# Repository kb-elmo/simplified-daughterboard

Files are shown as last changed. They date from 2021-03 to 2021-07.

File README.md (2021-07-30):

# Simplified USB-C Daughterboard

[][cc-by-sa] [](https://opensource.com/resources/what-open-hardware)
<a href="https://ko-fi.com/kb_elmo">kofibadge</a>

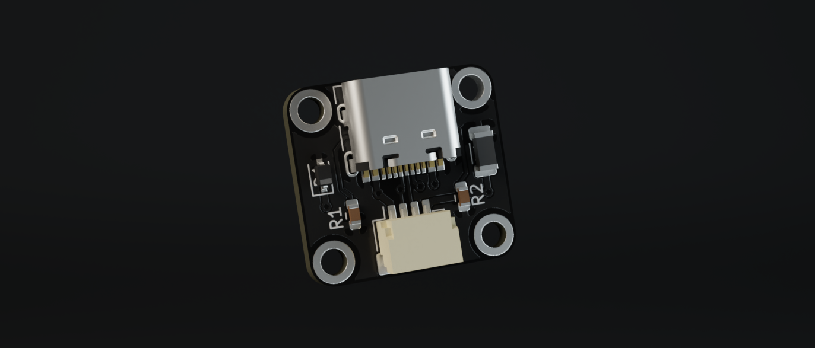
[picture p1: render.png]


This daughterboard features minimal electronics required for breaking out the VBUS, data and ground lines from a USB type C port.  
It includes a basic USB shielding circuit but has no ESD protection or fuse built in.

Fuse and (optional) ESD protection should be added on the main PCB if you want to use this for your project.

The daughterboard is pinout and size compatible with the [Unified Daughterboard by ai03](https://github.com/ai03-2725/Unified-Daughterboard).

Since the single PCB alone is too small for SMT assembly from JLCPCB and automatic panel assembly is currently not possible with them I created a 2x2 panelized version that works with JLCPCB assembly. You can find it in the fab files (linked below).

---

[Panelized PCB](fab/sDB_panel.kicad_pcb)

[Gerbers](fab/gerbers.zip)

[LCSC BOM](fab/bom.csv)

[JLC CPL](fab/pos.csv)

[USB connector](https://lcsc.com/product-detail/USB-Type-C_Korean-Hroparts-Elec-TYPE-C-31-M-12_C165948.html)

[JST connector](https://www.digikey.com/product-detail/en/jst-sales-america-inc/SM04B-SRSS-TB-LF-SN/455-1804-1-ND/926875)

---

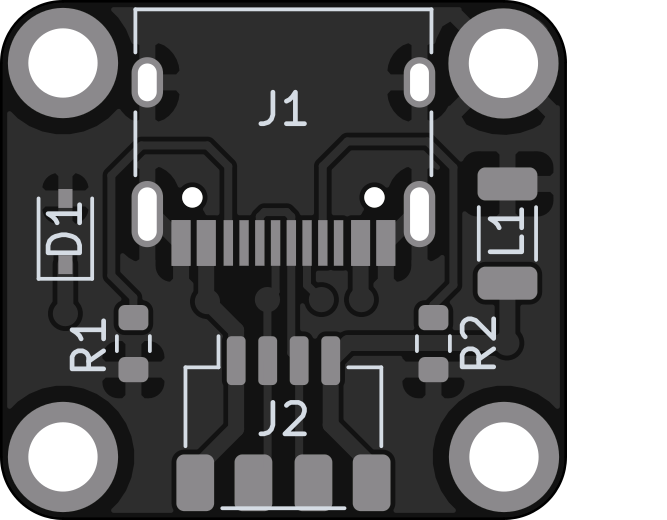
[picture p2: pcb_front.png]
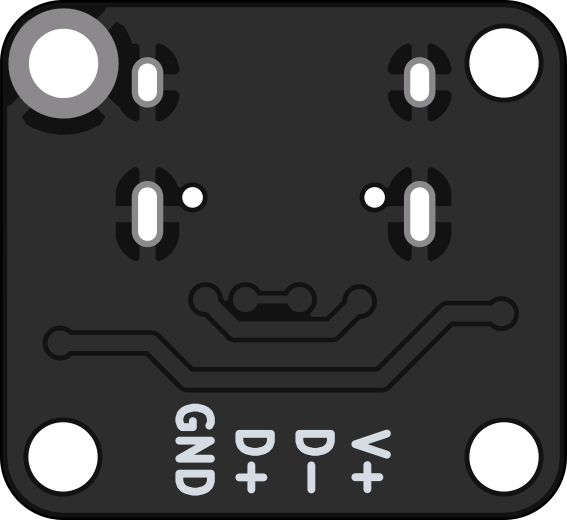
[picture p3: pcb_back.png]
 

This work is licensed under a
[Creative Commons Attribution-ShareAlike 4.0 International License][cc-by-sa].

[][cc-by-sa]

[cc-by-sa]: http://creativecommons.org/licenses/by-sa/4.0/
[cc-by-sa-image]: https://licensebuttons.net/l/by-sa/4.0/88x31.png
[cc-by-sa-shield]: https://img.shields.io/badge/License-CC%20BY--SA%204.0-lightgrey.svg
[os-love]: https://badges.frapsoft.com/os/v2/open-source.png?v=103

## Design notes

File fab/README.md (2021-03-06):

## Panelized PCB for JLCPCB SMT assembly
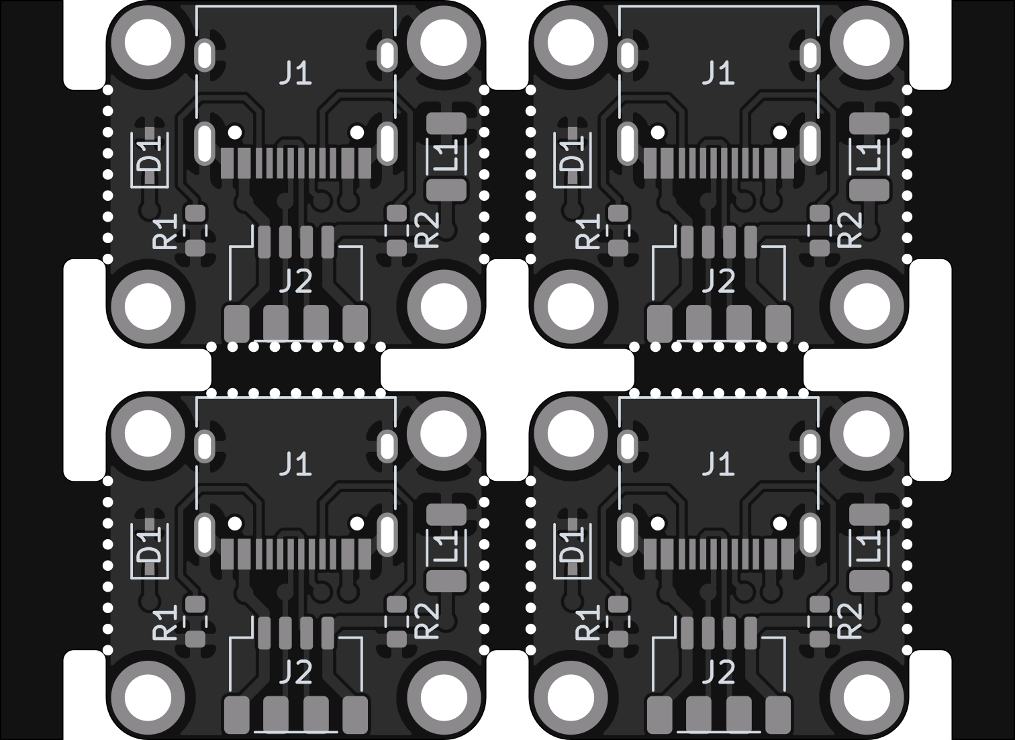
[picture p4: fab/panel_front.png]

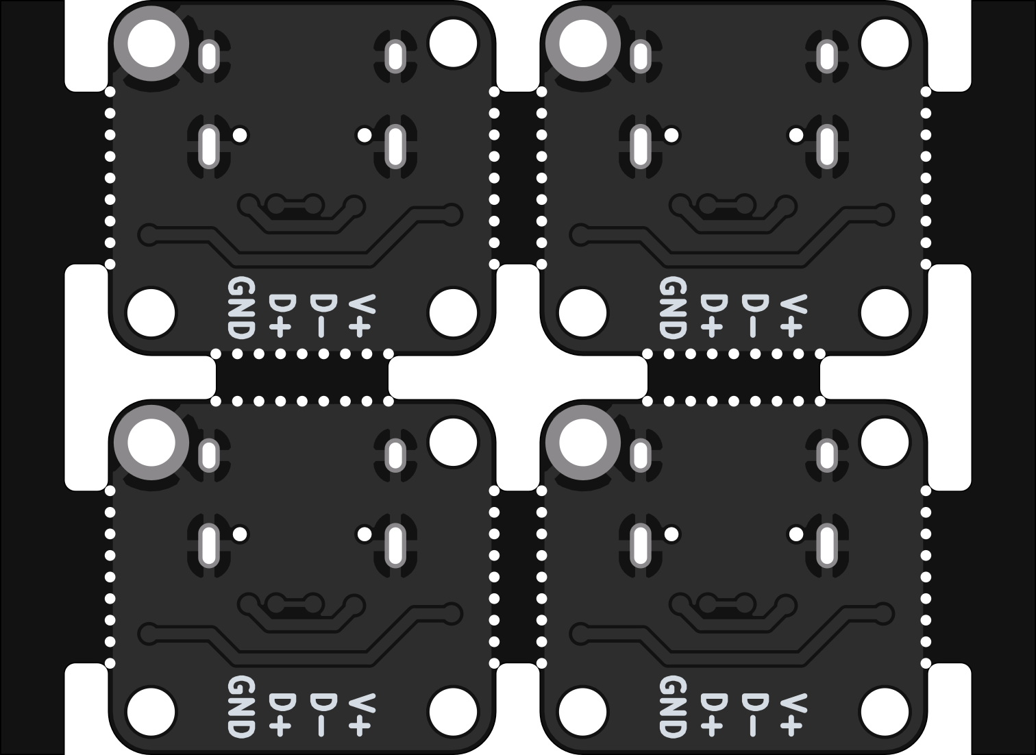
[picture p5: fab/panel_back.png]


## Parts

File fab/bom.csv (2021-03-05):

Comment | Designator | Footprint | LCSC
Conn_01x04 | J2 | custom_parts:JST_SH_SM04B-SRSS-TB_1x04-1MP_P1.00mm_Horizontal
USB_C_Receptacle_USB2.0 | J1 | Connector_USB:USB_C_Receptacle_HRO_TYPE-C-31-M-12 | C165948
5.6k | R1,R2 | Resistor_SMD:R_0603_1608Metric | C23189
L_Core_Ferrite | L1 | Inductor_SMD:L_1206_3216Metric | C33600
D_TVS | D1 | Diode_SMD:D_SOD-323 | C151996
MountingHole_Pad | H1 | custom_parts:Generic-Mounthole-dual
MountingHole | H2,H3,H4 | custom_parts:Generic-Mounthole

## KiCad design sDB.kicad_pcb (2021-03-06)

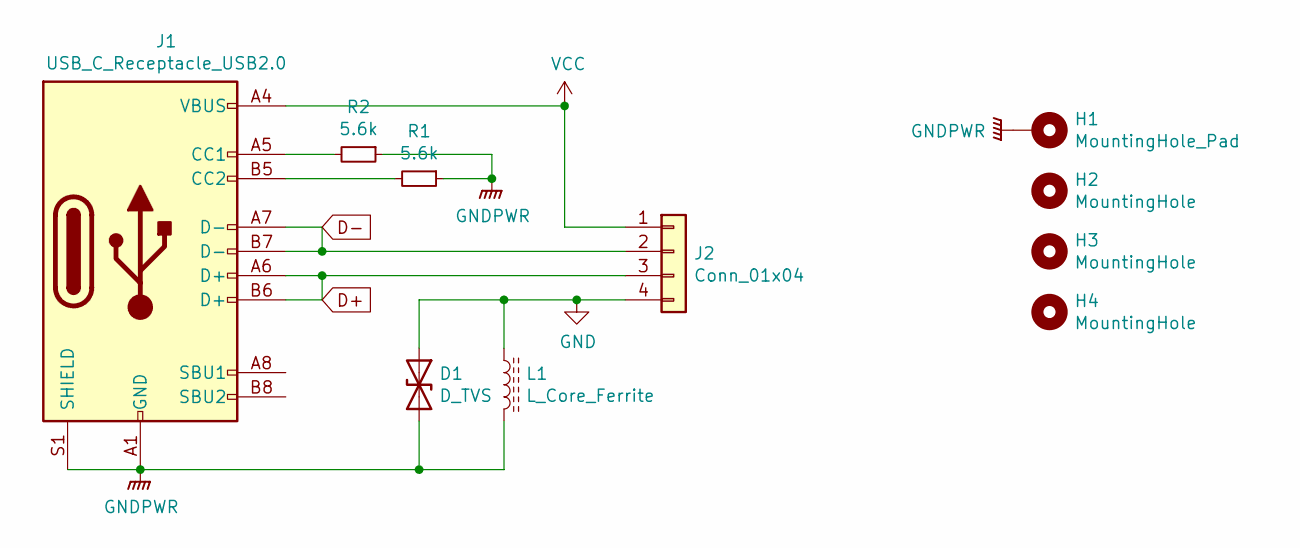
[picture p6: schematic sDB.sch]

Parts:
D1: D_TVS; D_SOD-323; LCSC C151996
H1: MountingHole_Pad; Generic-Mounthole-dual
H2, H3, H4: MountingHole; Generic-Mounthole
J1: USB_C_Receptacle_USB2.0; USB_C_Receptacle_HRO_TYPE-C-31-M-12; LCSC C165948
J2: Conn_01x04; JST_SH_SM04B-SRSS-TB_1x04-1MP_P1.00mm_Horizontal
L1: L_Core_Ferrite; L_1206_3216Metric; LCSC C33600
R1, R2: 5.6k; R_0603_1608Metric; LCSC C23189

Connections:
D+: J1.A6 (D+), J1.B6 (D+), J2.3
D-: J1.A7 (D-), J1.B7 (D-), J2.2
GND: D1.1 (A1), J2.4, L1.1
GNDPWR: D1.2 (A2), H1.1, J1.A1 (GND), J1.A12 (GND), J1.B1 (GND), J1.B12 (GND), J1.S1 (SHIELD), L1.2, R1.1, R2.1
unnamed: J1.A5 (CC1), R2.2
unnamed: J1.B5 (CC2), R1.2
VCC: J1.A4 (VBUS), J1.A9 (VBUS), J1.B4 (VBUS), J1.B9 (VBUS), J2.1

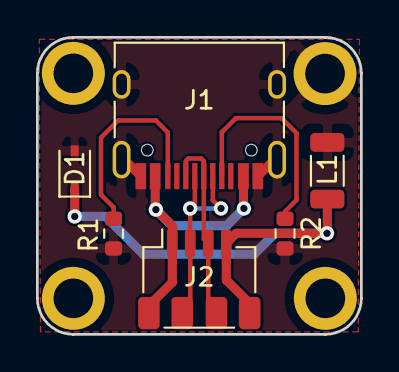
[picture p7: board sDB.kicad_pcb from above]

Board: 2 copper layers, 18.0 x 16.5 mm, 10 parts (0 on the bottom side), 7 nets.

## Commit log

2021-03-05 change image
    [sDB.kicad_pcb]
2021-03-06 remove logo
    [sDB.kicad_pcb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]
2021-03-06 add pinout labels
    [sDB.kicad_pcb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]

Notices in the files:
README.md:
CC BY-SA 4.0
